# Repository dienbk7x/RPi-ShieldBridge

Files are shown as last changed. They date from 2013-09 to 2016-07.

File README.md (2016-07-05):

# RPi-ShieldBridge
Raspberry Pi 1 A/B to Uno Shield Bridge.

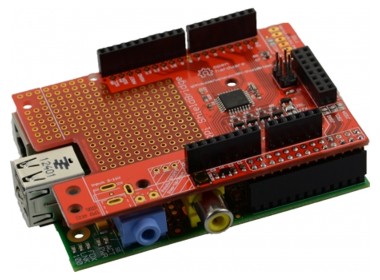
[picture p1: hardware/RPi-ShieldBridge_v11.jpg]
RPi-ShieldBridge (http://www.watterott.com/en/RPi-ShieldBridge)


## Shop
* [RPi-ShieldBridge for Raspberry Pi 1 Model A and B](http://www.watterott.com/en/RPi-ShieldBridge)

## Features
* Atmel AVR ATmega328 with Arduino compatible Bootloader (optiboot)
* Raspberry Pi connected via I2C and UART (to the AVR through level-shifter)
* AVR-Programming via Raspberry Pi possible
* Shield connectors with Uno R3 layout
* Additional 3.3V LDO voltage regulator for Shields
* Prototyping Area
* Optional MI0283QT-Adapter (2.8" 320x240 Display with Touchscreen/Touchpanel)
* Optional 3-11V power input for Raspberry Pi and ShieldBridge (Pololu S7V7F5)

## Hardware
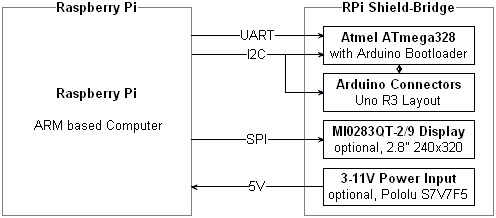
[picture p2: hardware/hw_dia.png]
RPi-ShieldBridge hardware dia
* 
* [Schematics + Layout](https://github.com/watterott/RPi-ShieldBridge/tree/master/hardware)

## Software
* [How to install the Arduino IDE on Raspberry Pi](https://github.com/watterott/RPi-ShieldBridge/blob/master/docu/Arduino.md)
* [How to control the RPi-ShieldBridge with Firmata](https://github.com/watterott/RPi-ShieldBridge/blob/master/docu/Firmata.md)
* [How to communicate with the RPi-ShieldBridge via I2C](https://github.com/watterott/RPi-ShieldBridge/blob/master/docu/I2CTest.md)
* [How to use a MI0283QT-Adapter (2.8" Display with Touchpanel)](https://github.com/watterott/RPi-ShieldBridge/blob/master/docu/MI0283QT-Adapter.md)
* [Nuage a Arduino Yún compatible device](http://www.arduino-hausautomation.de/nuage/)

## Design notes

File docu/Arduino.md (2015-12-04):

# Arduino IDE on Raspberry Pi with RPi-ShieldBridge

How to install the Arduino IDE on the Raspberry Pi to use with the RPi-ShieldBridge.

* Close the Jumpers: **JTX**, **JRX** and **JBL** on the RPi-ShieldBridge.

* Install the Arduino IDE:

    ```
    $ sudo apt-get update
    $ sudo apt-get install arduino
    ```

* Install [Auto-Reset for AVRdude](https://github.com/CisecoPlc/avrdude-rpi) on GPIO18 (Pin 12):

    ```
    $ wget https://github.com/watterott/RPi-ShieldBridge/raw/master/docu/autoreset
    $ wget https://github.com/watterott/RPi-ShieldBridge/raw/master/docu/avrdude-autoreset
    $ chmod +x autoreset
    $ chmod +x avrdude-autoreset
    $ sudo mv autoreset /usr/bin
    $ sudo mv avrdude-autoreset /usr/bin
    $ sudo mv /usr/bin/avrdude /usr/bin/avrdude-original
    $ sudo ln -s /usr/bin/avrdude-autoreset /usr/bin/avrdude
    ```

* [Disable Linux serial console](http://elinux.org/RPi_Serial_Connection#Preventing_Linux_using_the_serial_port):

    ```
    $ sudo raspi-config
    ```

    Select:
    ```
    Advanced > Disable shell and kernel messages on the serial connection.
    ```

    Reboot the system:
    ```
    $ sudo reboot
    ```

  * If there are any problems the changes can also be made with nano:
        ```
        $ sudo nano /boot/cmdline.txt
        ```
        Remove references to ```console=ttyAMA0,115200``` and ```kgdboc=ttyAMA0,115200```.

        ```
        $ sudo nano /etc/inittab
        ```
        Remove or comment the line ```T0:23:respawn:/sbin/getty -L ttyAMA0 115200 vt100```.

* Test AVRdude:

    ```
    $ sudo avrdude -c arduino -p m328p -P /dev/ttyAMA0 -b 57600 -v
    ```

    The device signature of the ATmega328 is *0x1e950f*.

* Run the Arduino IDE.

* Select **Arduino Uno** under **Tools->Board**.

* Select the hardware serial port **/dev/ttyAMA0** under **Tools->Serial Port**.

    If the hardware serial port is not recognized then create a symlink to the standard Linux serial port *ttyS0*:

    ```
    $ sudo nano /etc/udev/rules.d/80-arduinopi.rules

    KERNEL=="ttyAMA0", SYMLINK+="ttyS0",GROUP="dialout",MODE:=0666
    ```

    Another problem can be if the user, that runs the Arduino IDE, is not a member of the dialout group ([further infos](http://elinux.org/RPi_Serial_Connection)).
    To add a user to the group run:

    ```
    $ sudo usermod -a -G dialout USERNAME
    ```

* Open the Blink Sketch under **File->Examples->01.Basics->Blink**.

* Start build and upload: **File->Upload**.

* The LED on the RPi-ShieldBridge will start to blink after the upload is finished.

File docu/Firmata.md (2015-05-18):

# Firmata

[Firmata](http://firmata.org) is a protocol for communicating with microcontrollers from software on a host computer.
So you can control an Arduino with a Raspberry Pi using Firmata.

There is a tutorial for Firmata and Raspberry Pi in [The MagPi Issue 7](http://www.themagpi.com/en/issue/7) and here is also a small guide.

## Prepare RPi-ShieldBridge

* **Sketch upload with USB FTDI adapter**
  * Download and install the [Arduino IDE](http://arduino.cc/en/Main/Software) on your computer or [Raspberry Pi](https://github.com/watterott/RPi-ShieldBridge/blob/master/docu/Arduino.md).
  * Close the **JVCC Jumper** next to the FTDI connector to power the RPi-ShieldBridge from the FTDI adapter or put it on a Raspberry Pi for powering. 
  * Connect the RPi-ShieldBridge with a FTDI adapter (5V) to the computer or Raspberry Pi.
  * Start the Arduino IDE.
  * Select **Arduino Uno** under **Tools->Board**.
  * Choose the serial port from the FTDI adapter under **Tools->Serial Port**.
  * Open the Firmata Sketch under **File->Examples->Firmata->StandardFirmata**.
  * Start build and upload: **File->Upload**.
    If there are upload problems then add a pull-down resistor (10k-47k Ohm) between **GPIO18** or **Jumper JBL** and GND.
  * Now exit the Arduino IDE.

* **Sketch upload via hardware serial port of the Raspberry Pi**
  * Close the Jumpers: **JTX**, **JRX** and **JBL** on the RPi-ShieldBridge.
  * [Install the Arduino IDE on the Raspberry Pi](https://github.com/watterott/RPi-ShieldBridge/blob/master/docu/Arduino.md).
  * Run the Arduino IDE.
  * Select **Arduino Uno** under **Tools->Board**.
  * Select the hardware serial port **/dev/ttyAMA0** under **Tools->Serial Port**.
  * Open the Firmata Sketch under **File->Examples->Firmata->StandardFirmata**.
  * Upload the Sketch.
  * Now exit the Arduino IDE.

## Prepare Raspberry Pi

The RPi-ShieldBridge can be connected via USB or UART:

* **USB connection (FTDI adapter)**
  * Put the RPi-ShieldBridge on the Raspberry Pi.
  * Connect a FTDI adapter (5V) to the USB port of the Raspberry Pi and FTDI connector on the RPi-ShieldBridge.
  * Device name: */dev/ttyUSB0* or */dev/ttyACM0*

* **UART connection (hardware serial port)**
  * Close the **Jumpers JTX and JRX** on the RPi-ShieldBridge.
  * Put the RPi-ShieldBridge on the Raspberry Pi.
  * [Disable Linux serial console](http://elinux.org/RPi_Serial_Connection#Preventing_Linux_using_the_serial_port).
  * Device name: */dev/ttyAMA0*

## Controlling with Python

* Install [pySerial](http://pyserial.sourceforge.net) and [pyFirmata](https://github.com/tino/pyFirmata) using [pip](http://www.pip-installer.org/en/latest/installing.html):

    ```
    $ sudo apt-get update
    $ sudo apt-get install python-serial
    $ sudo pip install pyfirmata
    ```

* Create a test script named [Firmata.py](https://github.com/watterott/RPi-ShieldBridge/raw/master/docu/Firmata.py):

    ```
    $ nano Firmata.py

    import time
    import RPi.GPIO as GPIO
    import pyfirmata
    
    GPIO.setmode(GPIO.BOARD)
    GPIO.setup(12, GPIO.OUT)   # GPIO18 output
    GPIO.output(12, GPIO.LOW)  # GPIO18 low -> Arduino reset off
    
    # start connection to Arduino
    #  USB: /dev/ttyUSB0 or /dev/ttyACM0
    #  UART: /dev/ttyAMA0
    board = pyfirmata.Arduino('/dev/ttyAMA0')
    
    board.digital[13].write(1) # switch on LED
    time.sleep(3)              # 3s delay
    board.digital[13].write(0) # switch off LED
    time.sleep(3)              # 3s delay
    board.exit()
    ```

* Run the script:

    ```
    $ python Firmata.py
    ```

## Controlling with Node.js (JavaScript)

* Install [Node](http://elinux.org/Node.js_on_RPi), [Firmata library](https://npmjs.org/package/firmata) and [rpio library](https://npmjs.org/package/rpio):

    ```
    $ sudo apt-get install node
    $ sudo npm install -g firmata
    $ sudo npm install -g rpio
    ```
    If the *node* package is not found then add Adafruit to the package repository:
    ```curl -sLS https://apt.adafruit.com/add | sudo bash```

* Create a test script named [Firmata.js](https://github.com/watterott/RPi-ShieldBridge/raw/master/docu/Firmata.js):

    ```
    $ nano Firmata.js

    var rpio = require('rpio');
    var firmata = require('firmata');
    
    // GPIO18 low -> Arduino reset off
    rpio.setOutput(12);
    rpio.write(12, rpio.LOW);
    
    // start connection to Arduino
    //  USB: /dev/ttyUSB0 or /dev/ttyACM0
    //  UART: /dev/ttyAMA0
    var board = new firmata.Board('/dev/ttyAMA0', function(err)
    {
      if(err)
      {
        console.log(err);
        return;
      }
      console.log('connected');
      board.pinMode(13, board.MODES.OUTPUT);
      // switch on LED
      board.digitalWrite(13, board.HIGH);
      // switch off LED after 3s
      setTimeout(function()
      {
        board.digitalWrite(13, board.LOW);
        process.exit(0);
      }, 3000);
    });
    ```

* Run the script:

    ```
    $ sudo node Firmata.js
    ```

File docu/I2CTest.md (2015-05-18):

# I2C Test

A small guide to show the communication via I2C between the RPi-ShieldBridge and Raspberry Pi.

The I2C pins of the Raspberry Pi are connected to the AVR and the Shield connectors (SDA+SCL) on the RPi-ShieldBridge. 

## Prepare RPi-ShieldBridge

Upload the following [Sketch](https://github.com/watterott/RPi-ShieldBridge/raw/master/docu/I2CTest.ino):
```
#include <Wire.h> 

#define ADDRESS 0x30

void setup() 
{
  pinMode(13, OUTPUT);     // set pin 13 as output (LED connected)
  digitalWrite(13, LOW);   // set pin 13 to low (0V)

  Wire.begin(ADDRESS);     // join I2C bus with respective address
  Wire.onReceive(receive); // receive data function
  Wire.onRequest(request); // send data function
} 

void loop() 
{
  // do nothing
} 

void receive(int numBytes) // function that runs when data is received
{
  unsigned char c;

  while(Wire.available())
  { 
    c = Wire.read();
    if(c == 0x00)      // LED off, if byte equals 0
    {
      digitalWrite(13, LOW);
    }
    else if(c == 0x01) // LED on, if byte equals 1
    {
      digitalWrite(13, HIGH);
    }
  }
}

void request() // function that runs when data is requested
{
  Wire.write(0xAA); // send 0xAA
}
```

## Prepare Raspberry Pi

* Activate I2C:

    ```
    $ sudo modprobe i2c_bcm2708 baudrate=100000
    $ sudo modprobe i2c-dev
    ```
    Note: For a Device Tree Kernel add to ```/boot/config.txt``` the following line: ```dtparam=i2c1=on``` (before any dtoverlay statement).

* Install i2c-tools and python-smbus:

    ```
    $ sudo apt-get install i2c-tools
    $ sudo apt-get install python-smbus
    ```

* Test I2C bus:

    ```
    $ sudo i2cdetect -y 1
    ```

   *The Raspberry Pi hardware revision 1 boards connect I2C bus 0 (GPIO 0 + 1) and revision 2 boards connect I2C bus 1 (GPIO 2 + 3) to the GPIO connector.*

* Note: As default the reset pin of the AVR is connected to GPIO18 (Pin 12) of the Raspberry Pi (GPIO18 high = reset on, GPIO18 low = reset off). To disable the reset:

    ```
    $ sudo -i
    $ echo 18 > /sys/class/gpio/export
    $ echo out > /sys/class/gpio/gpio18/direction
    $ echo 0 > /sys/class/gpio/gpio18/value
    $ exit
    ```

    Or if you have installed [WiringPi](http://wiringpi.com):

    ```
    $ gpio -g mode 18 out
    $ gpio -g write 18 0
    ```

### Shell

* Switch on LED:

    ```
    $ sudo i2cset -y 1 0x30 0x01
    ```

* Switch off LED:

    ```
    $ sudo i2cset -y 1 0x30 0x00
    ```

### Python

* Create a test script named [I2CTest.py](https://github.com/watterott/RPi-ShieldBridge/raw/master/docu/I2CTest.py):

    ```
    $ nano I2CTest.py

    import time
    import smbus
    bus = smbus.SMBus(1)
    addr = 0x30
    
    while True:
        bus.write_byte(addr, 0x01)
        print "on"
        time.sleep(1)
        bus.write_byte(addr, 0x00)
        print "off"
        time.sleep(1)
    ```

* Run the script:

    ```
    $ sudo python I2CTest.py
    ```

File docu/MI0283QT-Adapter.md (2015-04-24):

# MI0283QT-Adapter v1

There is a [Linux Framebuffer driver (FBTFT)](https://github.com/notro/fbtft) available for the display adapter with MI0283QT-2 (HX8347D) + MI0283QT-9 / -11 (ILI9341) display panel and the ADS7846 / TSC2046 touch controller has also a Linux device driver.

An installation guide can be found [here](https://github.com/watterott/RPi-Display/blob/master/docu/FBTFT-Install.md).

It is also possible to use the ready to run [SD-Card image for the RPi-Display](https://github.com/watterott/RPi-Display) with modified parameters.
The respective parameters can be found in the installation guide under *FBTFT Kernel Modules*.

**Further Infos/Tutorials**
* [MI0283QT9 + RPi-ShieldBridge](http://lallafa.de/blog/2013/07/watterotts-new-rpi-shieldbridge/)
* [MI0283QT9 + RPi-ShieldBridge (German)](http://www.mdtweb.de/index.php/projekte/mikroprozessoren/raspberry-pi/rpi-lcd-ansteuerung)
* [MI0283QT9 + RPi-ShieldBridge (German)](http://www.forum-raspberrypi.de/Thread-tutorial-watterott-mi0283qt-9a-am-pi-betreiben)
* [MI0283QT9 driver installation](http://lallafa.de/blog/2013/03/watterott-mi0283qt-9a-display-for-the-rasbperry-pi/)
* [MI0283QT2 driver installation](http://lallafa.de/blog/2013/03/watterott-display-on-raspberry-pi/)
* [ADS7846 driver installation](http://lallafa.de/blog/2013/03/adding-touch-support-for-the-mi0283qt-displays/)
* [MI0283QT9 and BeagleBone Black](https://github.com/notro/fbtft/wiki/BeagleBone-Black)

**Display Connection**
```
Display  Raspberry Pi
---------------------
LCD-LED  GPIO24
LCD-RST  GPIO23
LCD-CS   GPIO8  (CE0) [on RPi-ShieldBridge v1.0: CE1]
ADS-CS   GPIO7  (CE1) [on RPi-ShieldBridge v1.0: CE0]
ADS-IRQ  GPIO25 (close Jumper JIRQ, open Jumper JSDA+JSCL)
MISO     GPIO9  (MISO)
MOSI     GPIO10 (MOSI)
SCK      GPIO11 (SCK)
```

# MI0283QT-Adapter v2

There is an experimental [Linux Framebuffer driver (fbtft)](https://github.com/notro/fbtft) available for the display adapter v2 with ARM controller.

An installation guide can be found [here](https://github.com/watterott/RPi-Display/blob/master/docu/FBTFT-Install.md).

It is also possible to use the ready to run [SD-Card image for the RPi-Display](https://github.com/watterott/RPi-Display) with modified parameters.
The respective parameters can be found in the installation guide under *FBTFT Kernel Modules*.

**Display Connection**
```
Display  Raspberry Pi
---------------------
LCD-RST  GPIO23
LCD-CS   GPIO8  (CE0) [on RPi-ShieldBridge v1.0: CE1]
 --- SPI/SSI ---
MISO     GPIO9  (MISO)
MOSI     GPIO10 (MOSI)
SCK      GPIO11 (SCK)
 --- I2C ---
LCD-SDA  GPIO2  (SDA, close Jumper JSDA)
LCD-SCL  GPIO3  (SCL, close Jumper JSCL, open Jumper JIRQ)
```

*Note: The Raspberry Pi hardware revision 1 boards connect I2C bus 0 (GPIO 0 + 1) and revision 2 boards connect I2C bus 1 (GPIO 2 + 3) to the GPIO connector.*

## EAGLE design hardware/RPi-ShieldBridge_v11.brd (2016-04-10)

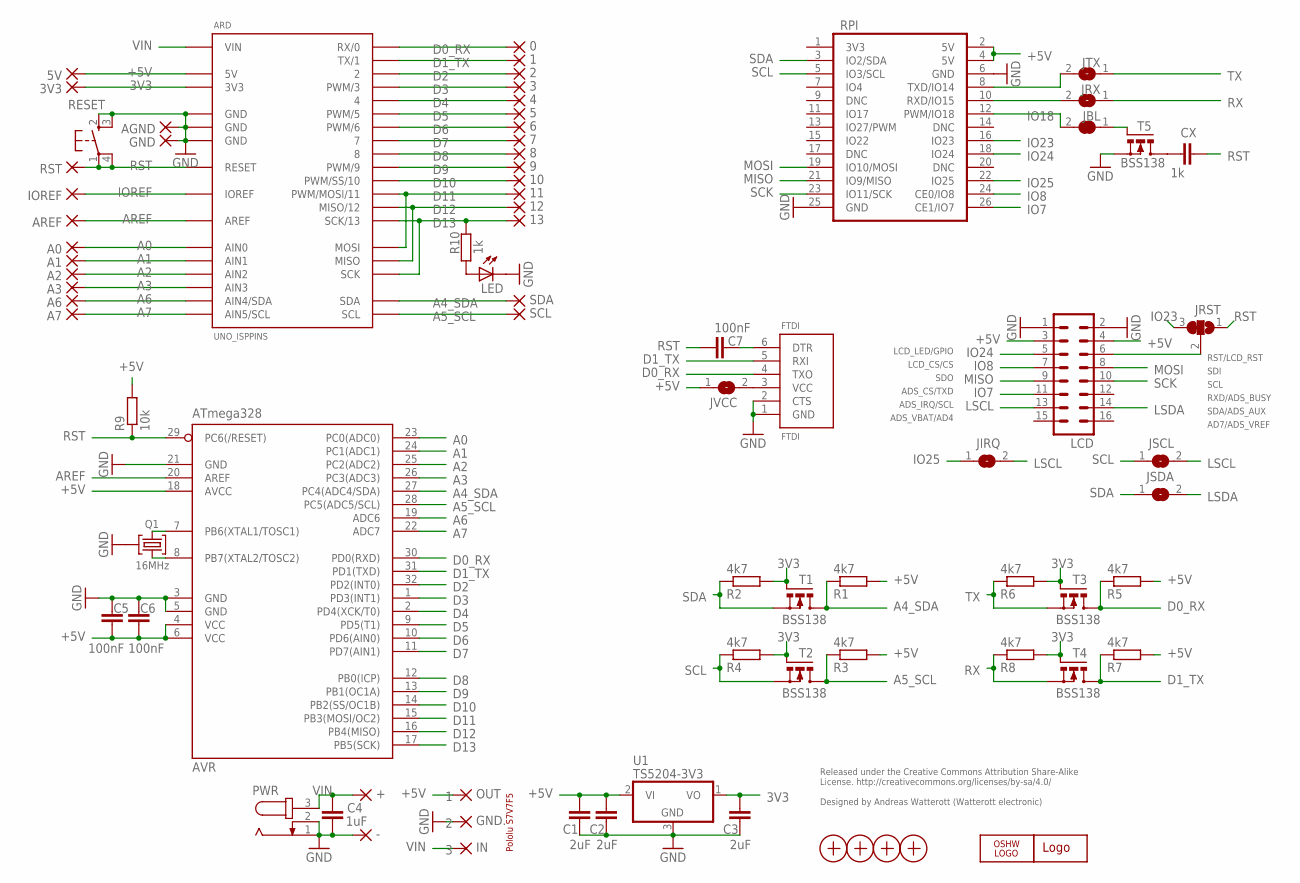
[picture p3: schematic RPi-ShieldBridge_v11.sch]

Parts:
0, 1, 2, 3, 3V3, 4, 5, 5V, 6, 7, 8, 9, 10, 11, 12, 13: WIREPAD1,6/0,9; 1,6/0,9
+: WIREPAD2,54/1,0; 2,54/1,0
-: WIREPAD2,54/1,0; 2,54/1,0
A0, A1, A2, A3, A6, A7: WIREPAD1,6/0,9; 1,6/0,9
AGND: WIREPAD1,6/0,9; 1,6/0,9
ARD: UNO_ISPPINS; UNO_ISP3
AREF: WIREPAD1,6/0,9; 1,6/0,9
AVR: ATmega328; TQFP32-08
C1, C2, C3: 2uF; C0603
C4: 1uF; C0603
C5, C6, C7: 100nF; C0603
CX: 1k; C0603
FTDI: FTDI
GND: WIREPAD1,6/0,9; 1,6/0,9
GND.: 2; 1,6/0,9
IN: 3; 1,6/0,9
IOREF: WIREPAD1,6/0,9; 1,6/0,9
JBL: SJ
JIRQ: SJ
JRST: SJ2W; SJ_2
JRX: SJ
JSCL: SJ
JSDA: SJ
JTX: SJ
JVCC: SJ
LCD: MA08-2
LED: LEDCHIPLED_0603; CHIPLED_0603
LOGO1: OSHW_LOGO_6MILX0150-NT; OSHW_6X150_NOTEXT
OUT: 1; 1,6/0,9
PWR: DC-JACK""; DC-JACK
Q1: 16MHz; SMD_OSC_35X15
R1, R2, R3, R4, R5, R6, R7, R8: 4k7; R0603
R9: 10k; R0603
R10: 1k; R0603
RESET: SW_SMDS; SW_SMD4@1
RPI: RPI
RST: WIREPAD1,6/0,9; 1,6/0,9
SCL: WIREPAD1,6/0,9; 1,6/0,9
SDA: WIREPAD1,6/0,9; 1,6/0,9
T1, T2, T3, T4, T5: BSS138; MICRO3
U1: TS5204-3V3; SOT23
U$1: WE-LOGO
X1, X2, X3, X4: PASSER

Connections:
3V3: 3V3.1, ARD.3V3, C3.1, R2.2, R4.2, R6.2, R8.2, T1.1 (G), T2.1 (G), T3.1 (G), T4.1 (G), U1.1 (VO)
+5V: 5V.1, ARD.5V, AVR.4 (VCC), AVR.6 (VCC), AVR.18 (AVCC), C1.1, C2.1, C5.1, C6.1, JVCC.1, LCD.3, LCD.4, OUT.1, R1.2, R3.2, R5.2, R7.2, R9.2, RPI.2 (5V), RPI.4 (5V), U1.2 (VI)
A0: A0.1, ARD.AIN0, AVR.23 (PC0(ADC0))
A1: A1.1, ARD.AIN1, AVR.24 (PC1(ADC1))
A2: A2.1, ARD.AIN2, AVR.25 (PC2(ADC2))
A3: A3.1, ARD.AIN3, AVR.26 (PC3(ADC3))
A4_SDA: ARD.SDA, AVR.27 (PC4(ADC4/SDA)), R1.1, SDA.1, T1.3 (D)
A5_SCL: ARD.SCL, AVR.28 (PC5(ADC5/SCL)), R3.1, SCL.1, T2.3 (D)
A6: A6.1, ARD.AIN4 (AIN4/SDA), AVR.19 (ADC6)
A7: A7.1, ARD.AIN5 (AIN5/SCL), AVR.22 (ADC7)
AREF: ARD.AREF, AREF.1, AVR.20 (AREF)
D0_RX: 0.1, ARD.0 (RX/0), AVR.30 (PD0(RXD)), FTDI.4 (TXO), R5.1, T3.3 (D)
D1_TX: 1.1, ARD.1 (TX/1), AVR.31 (PD1(TXD)), FTDI.5 (RXI), R7.1, T4.3 (D)
D2: 2.1, ARD.2, AVR.32 (PD2(INT0))
D3: 3.1, ARD.3 (PWM/3), AVR.1 (PD3(INT1))
D4: 4.1, ARD.4, AVR.2 (PD4(XCK/T0))
D5: 5.1, ARD.5 (PWM/5), AVR.9 (PD5(T1))
D6: 6.1, ARD.6 (PWM/6), AVR.10 (PD6(AIN0))
D7: 7.1, ARD.7, AVR.11 (PD7(AIN1))
D8: 8.1, ARD.8, AVR.12 (PB0(ICP))
D9: 9.1, ARD.9 (PWM/9), AVR.13 (PB1(OC1A))
D10: 10.1, ARD.10 (PWM/SS/10), AVR.14 (PB2(SS/OC1B))
D11: 11.1, ARD.11 (PWM/MOSI/11), ARD.MOSI, AVR.15 (PB3(MOSI/OC2))
D12: 12.1, ARD.12 (MISO/12), ARD.MISO, AVR.16 (PB4(MISO))
D13: 13.1, ARD.13 (SCK/13), ARD.SCK, AVR.17 (PB5(SCK)), R10.1
DTR: C7.1, FTDI.6 (DTR)
GND: -.1, AGND.1, ARD.GND@1 (GND), ARD.GND@2 (GND), ARD.GND@3 (GND), AVR.3 (GND), AVR.5 (GND), AVR.21 (GND), C1.2, C2.2, C3.2, C4.2, C5.2, C6.2, FTDI.1 (GND), FTDI.2 (CTS), GND.1, GND..1, LCD.1, LCD.2, LED.C, PWR.1, PWR.2, Q1.GND, RESET.2 (S), RESET.3 (S1), RPI.6 (GND), RPI.25 (GND), T5.2 (S), U1.3 (GND)
IO7: LCD.11, RPI.26 (CE1/IO7)
IO8: LCD.7, RPI.24 (CE0/IO8)
IO18: JBL.2, RPI.12 (PWM/IO18)
IO23: JRST.3, RPI.16 (IO23)
IO24: LCD.5, RPI.18 (IO24)
IO25: JIRQ.1, RPI.22 (IO25)
IOREF: ARD.IOREF, IOREF.1
LCD_RST: JRST.2, LCD.6
LSCL: JIRQ.2, JSCL.2, LCD.13
LSDA: JSDA.2, LCD.14
MISO: LCD.9, RPI.21 (IO9/MISO)
MOSI: LCD.8, RPI.19 (IO10/MOSI)
unnamed: AVR.8 (PB7(XTAL2/TOSC2)), Q1.2
unnamed: AVR.7 (PB6(XTAL1/TOSC1)), Q1.1
unnamed: CX.1, T5.3 (D)
unnamed: LED.A, R10.2
RPI_RST: JBL.1, T5.1 (G)
RST: ARD.RST (RESET), AVR.29 (PC6(/RESET)), C7.2, CX.2, JRST.1, R9.1, RESET.1, RESET.4 (P1), RST.1
RX: JRX.1, R8.1, T4.2 (S)
RX_IO15: JRX.2, RPI.10 (RXD/IO15)
SCK: LCD.10, RPI.23 (IO11/SCK)
SCL: JSCL.1, R4.1, RPI.5 (IO3/SCL), T2.2 (S)
SDA: JSDA.1, R2.1, RPI.3 (IO2/SDA), T1.2 (S)
TX: JTX.1, R6.1, T3.2 (S)
TX_IO14: JTX.2, RPI.8 (TXD/IO14)
VCC: FTDI.3 (VCC), JVCC.2
VIN: +.1, ARD.VIN, C4.1, IN.1, PWR.3

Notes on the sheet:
LCD_LED/GPIO
LCD_CS/CS
SDO
ADS_CS/TXD
ADS_IRQ/SCL
ADS_VBAT/AD4
AD7/ADS_VREF
SDA/ADS_AUX
RXD/ADS_BUSY
SCL
SDI
RST/LCD_RST
Pololu S7V7F5
Released under the Creative Commons Attribution Share-Alike License. http://creativecommons.org/licenses/by-sa/4.0/ Designed by Andreas Watterott (Watterott electronic)

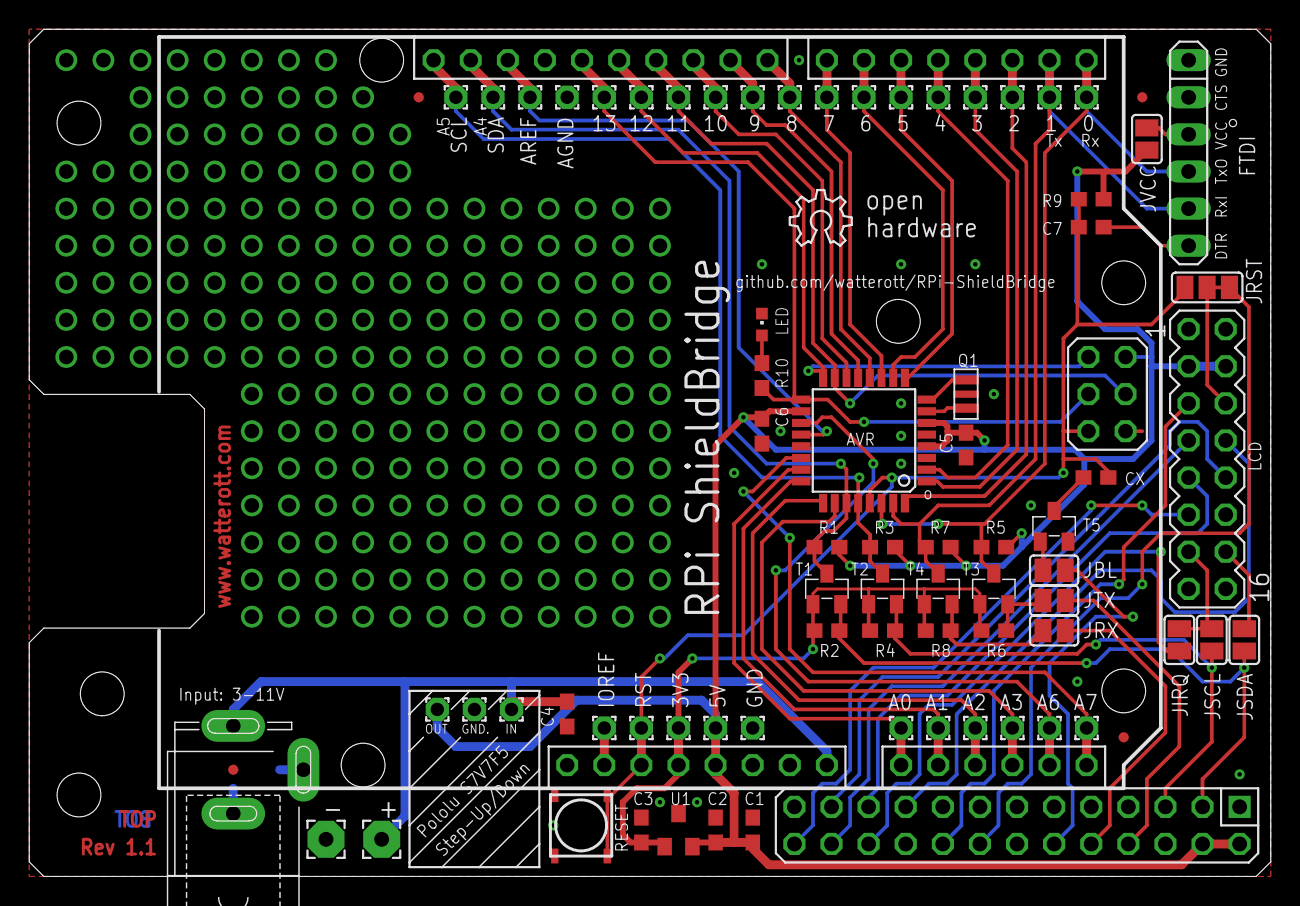
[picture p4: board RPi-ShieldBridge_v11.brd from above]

Board: 2 copper layers, 85.0 x 58.0 mm, 81 parts (1 on the bottom side), 54 nets.

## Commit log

2013-07-01 added rev 1.0 schematic and layout
    [RPi-ShieldBridge_v10.brd, RPi-ShieldBridge_v10.sch]
2013-08-01 added v1.1 pcb
    [RPi-ShieldBridge_v11.brd, RPi-ShieldBridge_v11.sch]
2013-08-11 updated v1.1
    [RPi-ShieldBridge_v11.brd, RPi-ShieldBridge_v11.sch]
2013-10-12 added I2C communication example
2013-10-12 added Arduino install guide
2014-03-05 Eagle v6 format
    [RPi-ShieldBridge_v10.brd, RPi-ShieldBridge_v10.sch, RPi-ShieldBridge_v11.brd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]
2014-08-15 updated schematic and layout files
    [RPi-ShieldBridge_v10.brd, RPi-ShieldBridge_v10.sch, RPi-ShieldBridge_v11.brd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]
2014-08-21 updated layout and schematics
    [RPi-ShieldBridge_v11.brd]
2014-11-06 cleaned up schematics and layout
    [RPi-ShieldBridge_v10.brd, RPi-ShieldBridge_v10.sch, RPi-ShieldBridge_v11.brd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]
2015-08-21 changed path structure
    [RPi-ShieldBridge_v10.brd, RPi-ShieldBridge_v10.sch, RPi-ShieldBridge_v11.brd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]
2016-04-10 updated schematics
    [RPi-ShieldBridge_v11.brd, RPi-ShieldBridge_v11.sch]
